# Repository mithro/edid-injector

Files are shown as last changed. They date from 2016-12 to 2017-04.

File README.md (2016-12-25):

A device for overriding / injecting EDID information into VGA/DVI/HDMI video
cables.

Based on the idea at
[vgaedidinjector](https://github.com/datenwolf/vgaedidinjector) but with a much
cheaper BOM. It shares no code or design elements with the original design
however.

Uses a Silicon Labs C8051F38x processor as;
 * Has two hardware I2C interfaces (input + output).
 * Has hardware USB subsystem.
 * Runs of 5V power with no external components.
 * Has internal oscillator.
 * I/O pins are 5V compatible.
 * Has good sdcc support.
 * Costs $1.83 USD in individual quantities.
 * Is hand solderable.

More info:
 * [Datasheet](http://www.silabs.com/Support%20Documents/TechnicalDocs/C8051F38x.pdf)
 * SiLab's part number: C8051F387-GQ
 * Digikey part Number: [336-2032-ND](http://www.digikey.com/product-detail/en/C8051F387-GQ/336-2032-ND/2601833)

# Other parts

## Connectors

 * HDMI connectors
  * **With** locking screw flange
   * `CONN RCPT HDMI W/FLANGE R/A SMD`
   * Manufacture part number: [FCI 10029449-002TLF]
   * Digikey part number: [609-1011-ND](http://www.digikey.com/product-search/en?KeyWords=609-1011-ND&WT.z_header=search_go)
   * [Datasheet](http://portal.fciconnect.com/Comergent//fci/drawing/10029449.pdf)
   * Product Image
   * Cost: $1.17 USD in individual quantities.

  * **Without** locking screw flange.
   * `CONN HDMI RECPT 19POS SMT R/A`
   * Manufacture part number: [FCI 10029449-111RLF]
   * Digikey part number: [609-4614-1-ND](http://www.digikey.com/product-detail/en/10029449-111RLF/609-4614-1-ND/2785376)
   * [Datasheet](http://portal.fciconnect.com/Comergent//fci/drawing/10029449.pdf)
   * Product Image
   * Cost: $0.73 USD in individual quantities.

# Editing

The designs in this repository was made using
[KiCad](http://www.kicad-pcb.org/) version **4.0.4**.

# License

Copyright 2014 Tim "mithro" Ansell licensed under a
Creative Commons Attribution-ShareAlike 4.0 International License.

You should have received a copy of the license along with this
work.  If not, see <http://creativecommons.org/licenses/by-sa/4.0/>.



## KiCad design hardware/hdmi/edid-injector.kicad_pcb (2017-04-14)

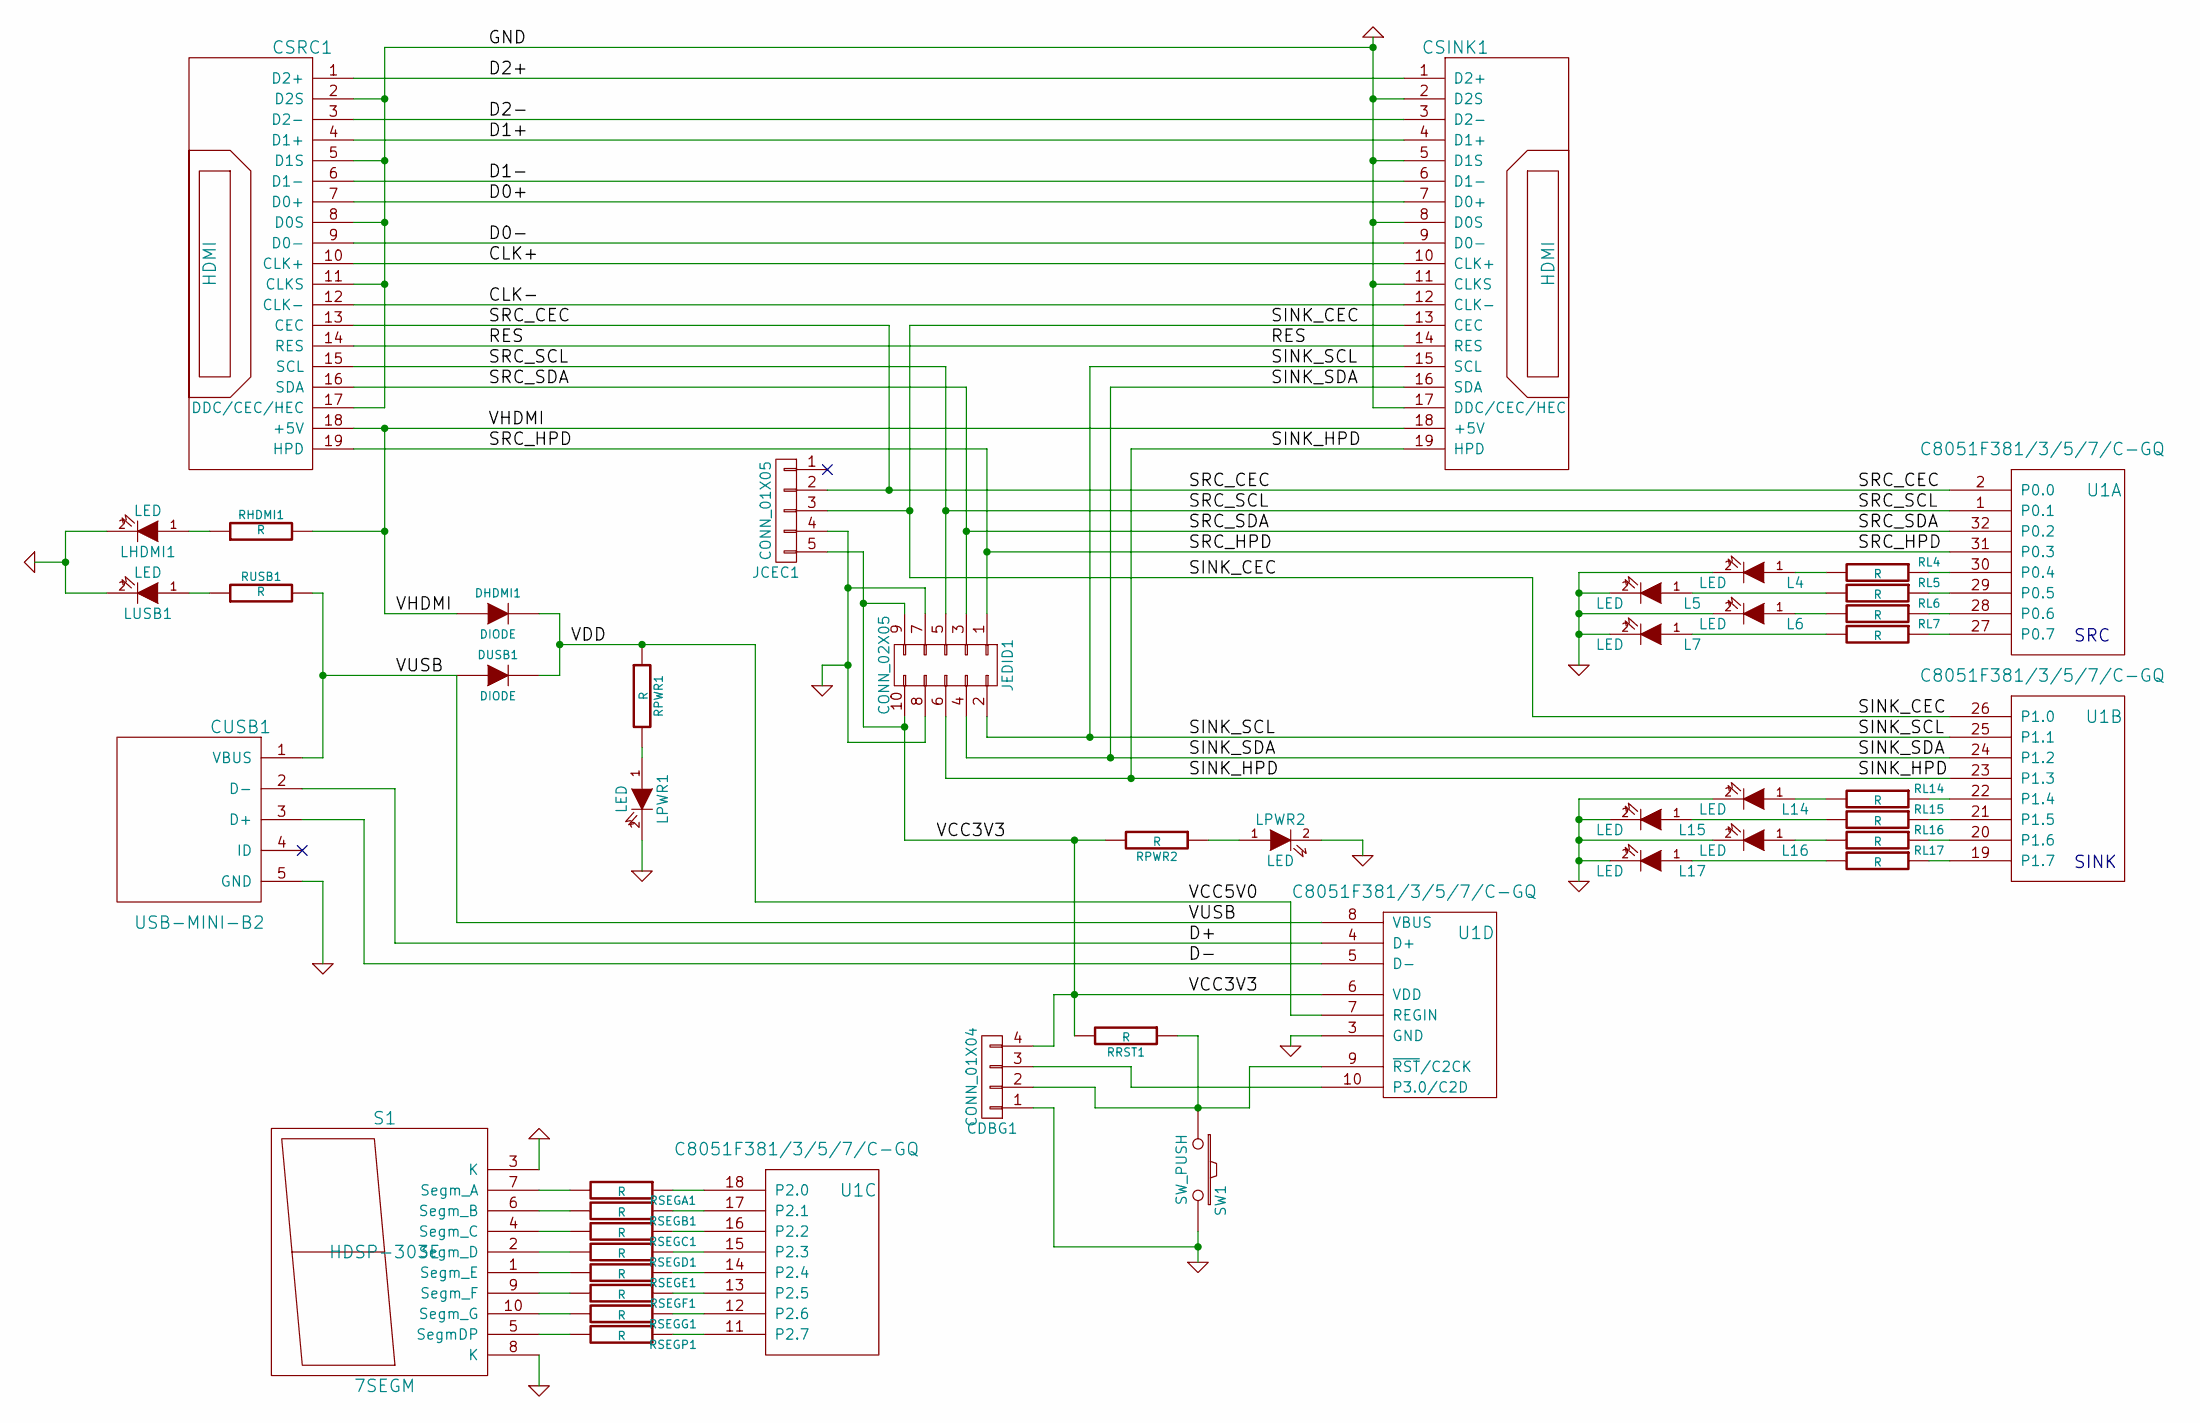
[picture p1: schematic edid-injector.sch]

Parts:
CDBG1: CONN_01X04; Pin_Header_Straight_1x04
CSINK1: HDMI; hdmi
CSRC1: HDMI; hdmi
CUSB1: USB-MINI-B2; micro-usb
DHDMI1: DIODE; sod323
DUSB1: DIODE; sod323
JCEC1: CONN_01X05; Pin_Header_Straight_1x05
JEDID1: CONN_02X05; Pin_Header_Straight_2x05
L4, L5, L6, L7, L14, L15, L16, L17: LED; LED_0805
LHDMI1: LED; LED_0805
LPWR1, LPWR2: LED; LED_0805
LUSB1: LED; LED_0805
RHDMI1: R; R_0402
RL4, RL5, RL6, RL7, RL14, RL15, RL16, RL17: R; R_0402
RPWR1, RPWR2: R; R_0402
RRST1: R; R_0402
RSEGA1: R; R_0402
RSEGB1: R; R_0402
RSEGC1: R; R_0402
RSEGD1: R; R_0402
RSEGE1: R; R_0402
RSEGF1: R; R_0402
RSEGG1: R; R_0402
RSEGP1: R; R_0402
RUSB1: R; R_0402
S1: 7SEGM; DIP-10__300
SW1: SW_PUSH; Pin_Header_Angled_1x02
U1: C8051F381/3/5/7/C-GQ; lqfp32

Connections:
/CLK+: CSINK1.10 (CLK+), CSRC1.10 (CLK+)
/CLK-: CSINK1.12 (CLK-), CSRC1.12 (CLK-)
/D0+: CSINK1.7 (D0+), CSRC1.7 (D0+)
/D0-: CSINK1.9 (D0-), CSRC1.9 (D0-)
/D1+: CSINK1.4 (D1+), CSRC1.4 (D1+)
/D1-: CSINK1.6 (D1-), CSRC1.6 (D1-)
/D2+: CSINK1.1 (D2+), CSRC1.1 (D2+)
/D2-: CSINK1.3 (D2-), CSRC1.3 (D2-)
/D+: CUSB1.2 (D-), U1.4 (D+)
/D-: CUSB1.3 (D+), U1.5 (D-)
/RES: CSINK1.14 (RES), CSRC1.14 (RES)
/SINK_CEC: CSINK1.13 (CEC), JCEC1.3, U1.26 (P1.0)
/SINK_HPD: CSINK1.19 (HPD), JEDID1.6, U1.23 (P1.3)
/SINK_SCL: CSINK1.15 (SCL), JEDID1.2, U1.25 (P1.1)
/SINK_SDA: CSINK1.16 (SDA), JEDID1.4, U1.24 (P1.2)
/SRC_CEC: CSRC1.13 (CEC), JCEC1.2, U1.2 (P0.0)
/SRC_HPD: CSRC1.19 (HPD), JEDID1.1, U1.31 (P0.3)
/SRC_SCL: CSRC1.15 (SCL), JEDID1.5, U1.1 (P0.1)
/SRC_SDA: CSRC1.16 (SDA), JEDID1.3, U1.32 (P0.2)
/VCC3V3: CDBG1.4, JCEC1.5, JEDID1.9, JEDID1.10, RPWR2.2, RRST1.2, U1.6 (VDD)
/VCC5V0: DHDMI1.2 (K), DUSB1.2 (K), RPWR1.1, U1.7 (REGIN)
/VHDMI: CSINK1.18 (+5V), CSRC1.18 (+5V), DHDMI1.1 (A), RHDMI1.2
/VUSB: CUSB1.1 (VBUS), DUSB1.1 (A), RUSB1.2, U1.8 (VBUS)
GND: CDBG1.1, CSINK1.2 (D2S), CSINK1.5 (D1S), CSINK1.8 (D0S), CSINK1.11 (CLKS), CSINK1.17 (DDC/CEC/HEC), CSRC1.2 (D2S), CSRC1.5 (D1S), CSRC1.8 (D0S), CSRC1.11 (CLKS), CSRC1.17 (DDC/CEC/HEC), CUSB1.5 (GND), JCEC1.4, JEDID1.7, JEDID1.8, L4.2 (K), L5.2 (K), L6.2 (K), L7.2 (K), L14.2 (K), L15.2 (K), L16.2 (K), L17.2 (K), LHDMI1.2 (K), LPWR1.2 (K), LPWR2.2 (K), LUSB1.2 (K), S1.3 (K), S1.8 (K), SW1.2, U1.3 (GND)
unnamed: CDBG1.2, RRST1.1, SW1.1, U1.9 (~RST~/C2CK)
unnamed: CDBG1.3, U1.10 (P3.0/C2D)
unnamed: L4.1 (A), RL4.2
unnamed: L5.1 (A), RL5.2
unnamed: L6.1 (A), RL6.2
unnamed: L7.1 (A), RL7.2
unnamed: L14.1 (A), RL14.2
unnamed: L15.1 (A), RL15.2
unnamed: L16.1 (A), RL16.2
unnamed: L17.1 (A), RL17.2
unnamed: LHDMI1.1 (A), RHDMI1.1
unnamed: LPWR1.1 (A), RPWR1.2
unnamed: LPWR2.1 (A), RPWR2.1
unnamed: LUSB1.1 (A), RUSB1.1
unnamed: RL4.1, U1.30 (P0.4)
unnamed: RL5.1, U1.29 (P0.5)
unnamed: RL6.1, U1.28 (P0.6)
unnamed: RL7.1, U1.27 (P0.7)
unnamed: RL14.1, U1.22 (P1.4)
unnamed: RL15.1, U1.21 (P1.5)
unnamed: RL16.1, U1.20 (P1.6)
unnamed: RL17.1, U1.19 (P1.7)
unnamed: RSEGA1.1, U1.18 (P2.0)
unnamed: RSEGA1.2, S1.7 (Segm_A)
unnamed: RSEGB1.1, U1.17 (P2.1)
unnamed: RSEGB1.2, S1.6 (Segm_B)
unnamed: RSEGC1.1, U1.16 (P2.2)
unnamed: RSEGC1.2, S1.4 (Segm_C)
unnamed: RSEGD1.1, U1.15 (P2.3)
unnamed: RSEGD1.2, S1.2 (Segm_D)
unnamed: RSEGE1.1, U1.14 (P2.4)
unnamed: RSEGE1.2, S1.1 (Segm_E)
unnamed: RSEGF1.1, U1.13 (P2.5)
unnamed: RSEGF1.2, S1.9 (Segm_F)
unnamed: RSEGG1.1, U1.12 (P2.6)
unnamed: RSEGG1.2, S1.10 (Segm_G)
unnamed: RSEGP1.1, U1.11 (P2.7)
unnamed: RSEGP1.2, S1.5 (SegmDP)

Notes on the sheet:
SRC
SINK

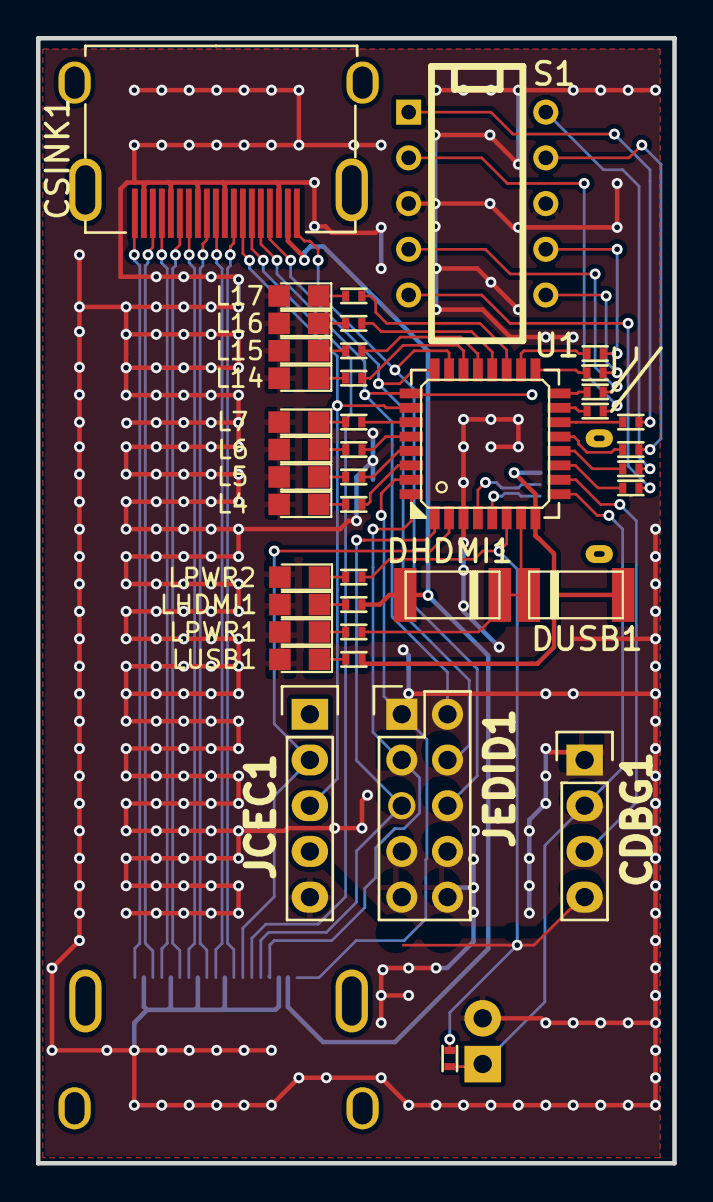
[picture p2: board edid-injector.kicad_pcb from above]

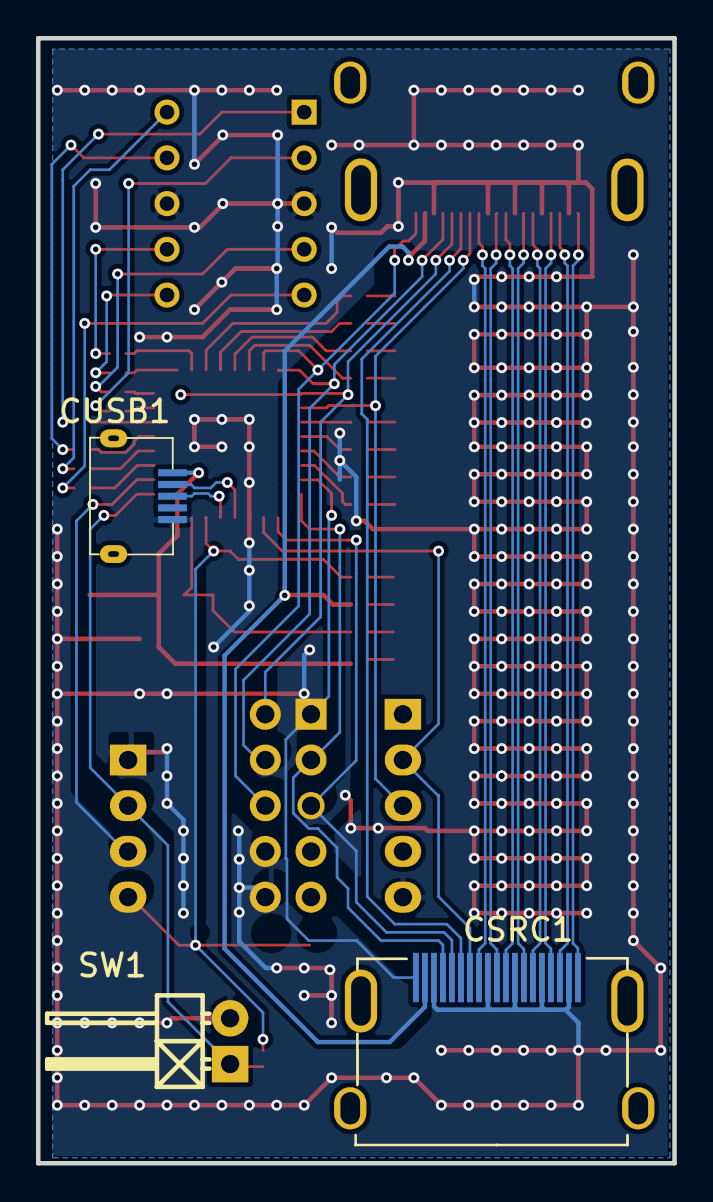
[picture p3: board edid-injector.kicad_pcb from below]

Board: 2 copper layers, 35.3 x 62.5 mm, 44 parts (3 on the bottom side), 62 nets.

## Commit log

2014-09-08 Initial schematic.
    [edid-injector.sch]
2014-11-04 Temporary commit to allow John to take a look at the design.
    [edid-injector.kicad_pcb, edid-injector.sch]
2014-11-04 Fix schematic no-connects and some electrical rules
    [edid-injector.sch]
2014-11-04 Begin PCB layout - cleaning up rats nest
    [edid-injector.kicad_pcb]
2014-11-15 Update 7-segment footprint and add Digikey Ref.
    [edid-injector.sch]
2014-11-15 Converging on sane placement for parts
    [edid-injector.kicad_pcb]
2014-11-15 Closer to an autorouter-friendly layout.
    [edid-injector.kicad_pcb]
2014-11-28 Better layout for PCB - autorouter is at -7 traces
    [edid-injector.kicad_pcb]
2014-11-28 Preliminary route.
    [edid-injector.kicad_pcb]
2014-11-30 Fixing the EDID jumper.
    [edid-injector.kicad_pcb, edid-injector.sch]
2014-11-30 Working on DRC info.
    [edid-injector.kicad_pcb]
2014-11-30 Update PCB
    [edid-injector.kicad_pcb]
2014-11-30 Connect everything up.
    [edid-injector.kicad_pcb]
2016-08-03 Old changes.
    [edid-injector.kicad_pcb]
2016-12-25 Moving things around slightly.
    [edid-injector.kicad_pcb, edid-injector.sch]
2016-12-25 Bunch of small tweaks.
    [edid-injector.sch]
2016-12-25 Fixing component assignments.
    [edid-injector.kicad_pcb, edid-injector.sch]
2017-04-14 First PCB design from Phyllis.
    [edid-injector.kicad_pcb]
2017-04-14 Trying to make things a little more uniform.
    [edid-injector.kicad_pcb, edid-injector.sch]
